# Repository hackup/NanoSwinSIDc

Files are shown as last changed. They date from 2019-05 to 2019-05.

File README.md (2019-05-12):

NanoSwinSIDc
============
**USE AT YOUR OWN RISK!**

The [SwinSID](http://www.swinkels.tvtom.pl/swinsid/) is a drop-in replacement for the MOS 6581 and
MOS 8580 sound chips. It is **not** fully compatible and it lacks certain
features.

The NanoSwinSIDc board layout was created using KiCAD and it is heavily based on
[the NanoSinSIDb](http://www.tolaemon.com/nss/) made by Tolaemon.

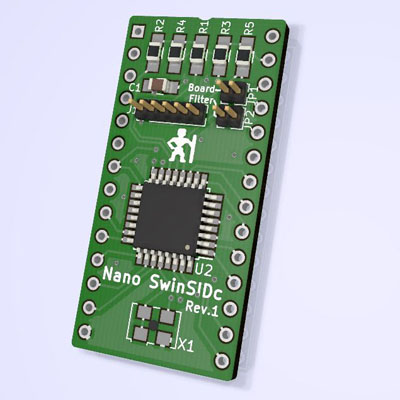
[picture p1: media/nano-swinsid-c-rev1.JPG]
NanoSinSIDc Rev.1


Revision 1 has been tested and can be confirmed working. Caveat: The Board/Filter labels for JP1/JP2 have accidentally been swapped!

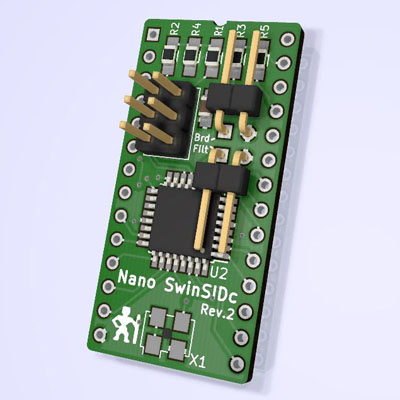
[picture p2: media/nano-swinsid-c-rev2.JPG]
NanoSinSIDc Rev.2


Revision 2 features an optimized layout with standard 100mil connectors. It has not yet been tested.

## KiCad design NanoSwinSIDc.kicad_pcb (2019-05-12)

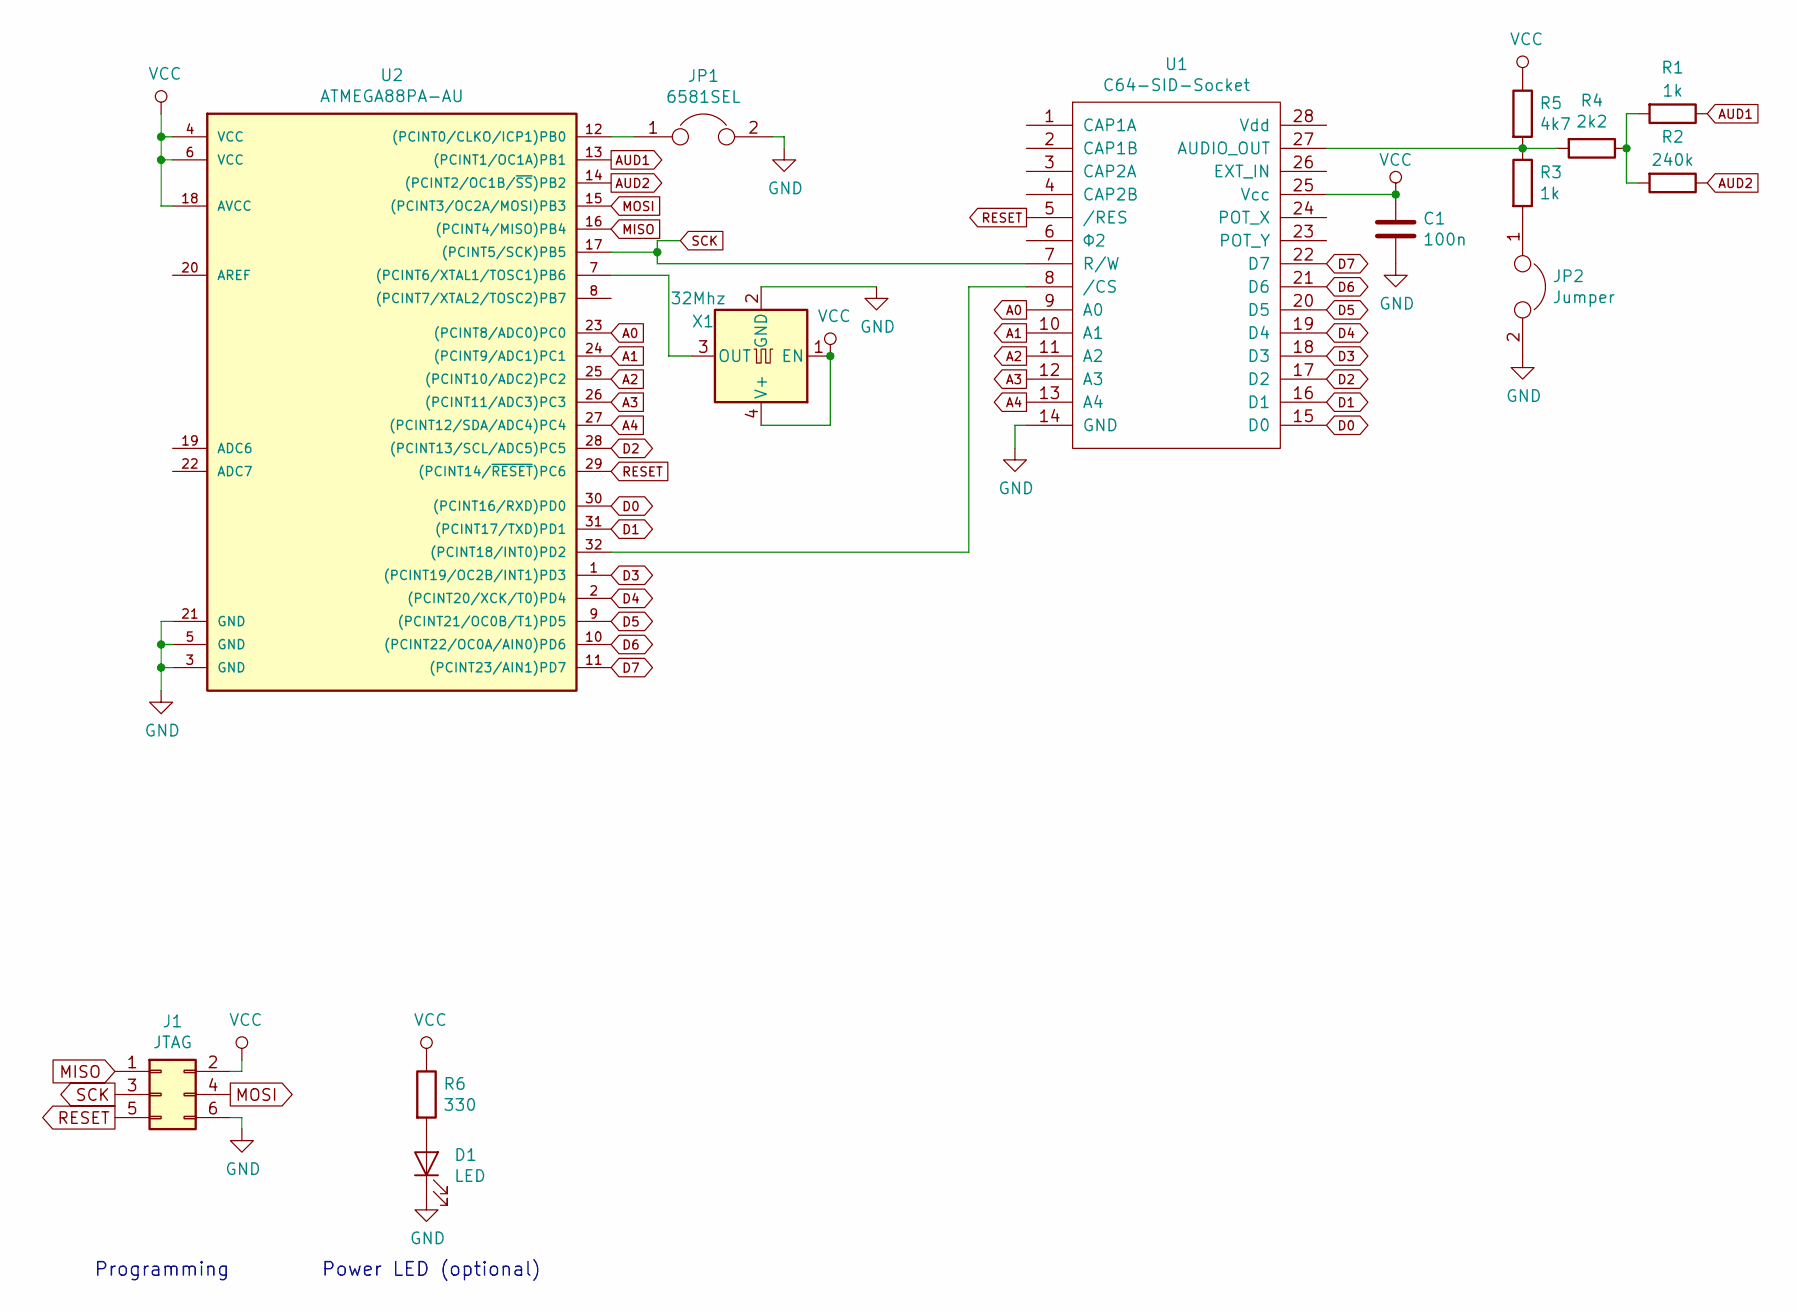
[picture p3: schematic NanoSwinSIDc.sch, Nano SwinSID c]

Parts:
C1: 100n; C_0805_HandSoldering
D1: LED; LED_0805_HandSoldering
J1: JTAG; Pin_Header_Straight_2x03_Pitch2.54mm
JP1: 6581SEL; Pin_Header_Angled_1x02_Pitch2.54mm
JP2: Jumper; Pin_Header_Angled_1x02_Pitch2.54mm
R1, R3: 1k; R_0805_HandSoldering
R2: 240k; R_0805_HandSoldering
R4: 2k2; R_0805_HandSoldering
R5: 4k7; R_0805_HandSoldering
R6: 330; R_0805_HandSoldering
U1: C64-SID-Socket; Socket-Adapter-DIP28
U2: ATMEGA88PA-AU; TQFP-32_7x7mm_Pitch0.8mm
X1: 32Mhz; Oscillator_SMD_EuroQuartz_XO53-4pin_5.0x3.2mm_HandSoldering

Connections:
A0: U1.9 (A0), U2.23 ((PCINT8/ADC0)PC0)
A1: U1.10 (A1), U2.24 ((PCINT9/ADC1)PC1)
A2: U1.11 (A2), U2.25 ((PCINT10/ADC2)PC2)
A3: U1.12 (A3), U2.26 ((PCINT11/ADC3)PC3)
A4: U1.13 (A4), U2.27 ((PCINT12/SDA/ADC4)PC4)
AUD1: R1.1, U2.13 ((PCINT1/OC1A)PB1)
AUD2: R2.1, U2.14 ((PCINT2/OC1B/~SS~)PB2)
D0: U1.15 (D0), U2.30 ((PCINT16/RXD)PD0)
D1: U1.16 (D1), U2.31 ((PCINT17/TXD)PD1)
D2: U1.17 (D2), U2.28 ((PCINT13/SCL/ADC5)PC5)
D3: U1.18 (D3), U2.1 ((PCINT19/OC2B/INT1)PD3)
D4: U1.19 (D4), U2.2 ((PCINT20/XCK/T0)PD4)
D5: U1.20 (D5), U2.9 ((PCINT21/OC0B/T1)PD5)
D6: U1.21 (D6), U2.10 ((PCINT22/OC0A/AIN0)PD6)
D7: U1.22 (D7), U2.11 ((PCINT23/AIN1)PD7)
GND: C1.2, D1.1 (K), J1.6, JP1.2, JP2.2, U1.14 (GND), U2.3 (GND), U2.5 (GND), U2.21 (GND), X1.2 (GND)
MISO: J1.1, U2.16 ((PCINT4/MISO)PB4)
MOSI: J1.4, U2.15 ((PCINT3/OC2A/MOSI)PB3)
unnamed: D1.2 (A), R6.2
unnamed: JP1.1, U2.12 ((PCINT0/CLKO/ICP1)PB0)
unnamed: JP2.1, R3.2
unnamed: R1.2, R2.2, R4.1
unnamed: R3.1, R4.2, R5.2, U1.27 (AUDIO_OUT)
unnamed: U1.8 (/CS), U2.32 ((PCINT18/INT0)PD2)
unnamed: U2.7 ((PCINT6/XTAL1/TOSC1)PB6), X1.3 (OUT)
RESET: J1.5, U1.5 (/RES), U2.29 ((PCINT14/~RESET~)PC6)
SCK: J1.3, U1.7 (R/W), U2.17 ((PCINT5/SCK)PB5)
VCC: C1.1, J1.2, R5.1, R6.1, U1.25 (Vcc), U2.4 (VCC), U2.6 (VCC), U2.18 (AVCC), X1.1 (EN), X1.4 (V+)

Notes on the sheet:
Power LED (optional)
Programming

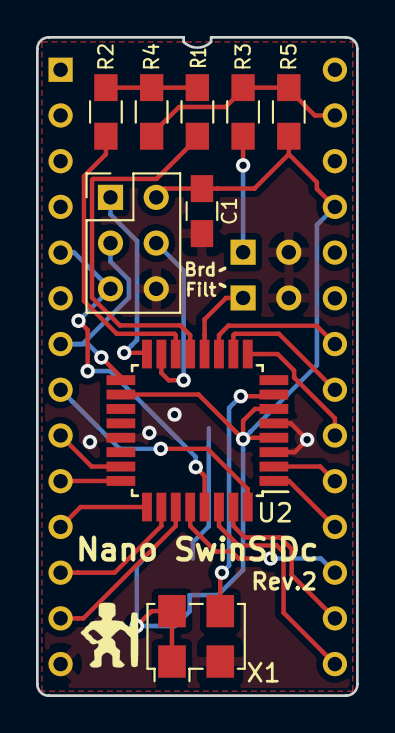
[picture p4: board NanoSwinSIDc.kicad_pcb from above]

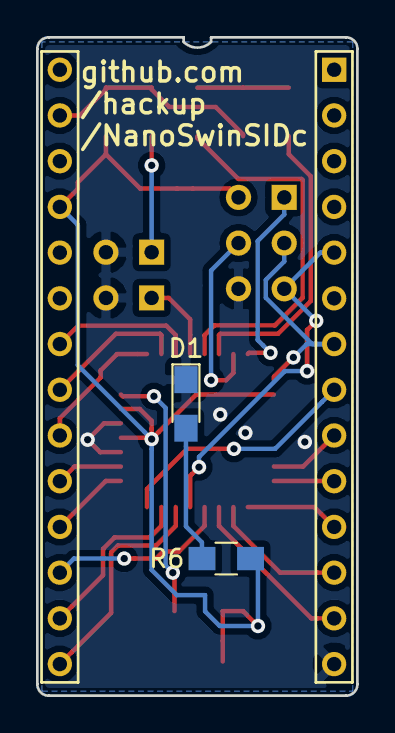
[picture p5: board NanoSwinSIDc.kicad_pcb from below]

Board: 2 copper layers, 17.8 x 36.6 mm, 14 parts (2 on the bottom side), 28 nets.

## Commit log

2018-04-09 Initial commit.
    [NanoSwinSIDc.kicad_pcb, NanoSwinSIDc.sch]
2018-04-12 Oscillator should have had a hand-soldering footprint.
    [NanoSwinSIDc.kicad_pcb, NanoSwinSIDc.sch]
2018-04-13 Corrected jumper labels.
    [NanoSwinSIDc.kicad_pcb]
2018-04-13 Replaced 50mil header with regular 100mil ones and adapted board layout.
    [NanoSwinSIDc.kicad_pcb, NanoSwinSIDc.sch]
2019-05-12 Library update.
    [NanoSwinSIDc.kicad_pcb, NanoSwinSIDc.sch]
